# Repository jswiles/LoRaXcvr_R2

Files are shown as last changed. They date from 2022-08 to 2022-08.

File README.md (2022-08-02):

# LoRa Transceiver

LoRa Transceiver PCB for LoRa Remote Monitor System

- STM32L15x MPU : 
    - 256K FlashMemory
    - 32K SRAM
    - RTC Support - 32Khz Crystal

- HopeRF RFM95W LoRa Module 
    - US 915Mhz (FCC certified)

- TTL RS-232 Debug Port

- ST-LINK SWDIO Programming header

- Input Voltage   
    - 5.2 to 10 volts DC (500mA max)

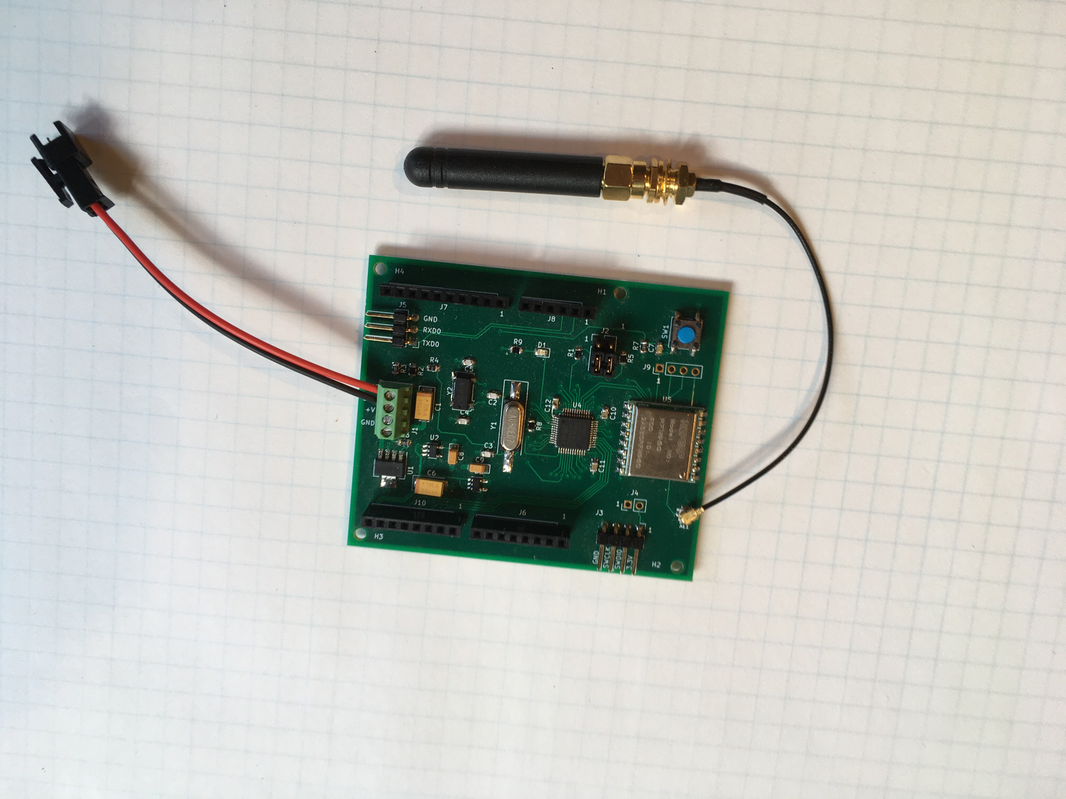
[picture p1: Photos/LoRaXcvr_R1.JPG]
LoRaXcvr_R1 Revision 1


Revision 1 

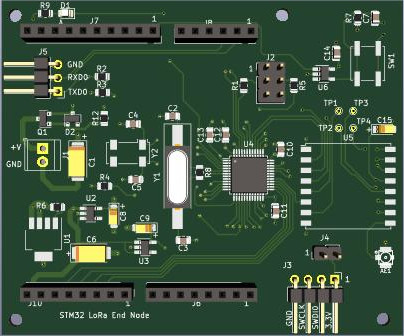
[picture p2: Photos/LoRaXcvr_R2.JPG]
LoRaXcvr_R2 Revision 2


Revision 2 3D Model

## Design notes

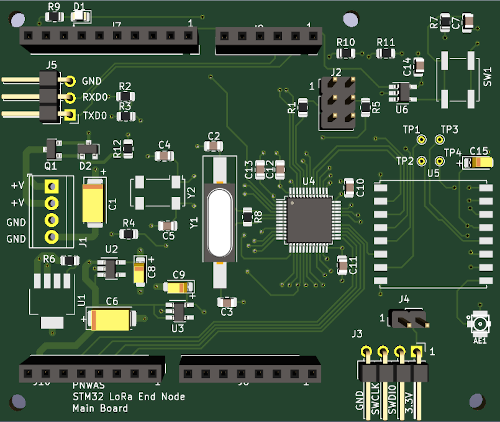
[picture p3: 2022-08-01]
Photos/LoRaXcvr_R2.png

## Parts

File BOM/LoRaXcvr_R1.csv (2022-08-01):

Reference | Quantity | Value | Footprint | Datasheet | DigiKey
AE1 | 1 | Antenna_Shield | connector-ufl:U.FL-COAX | ~ | CONUFL001-SMD-T
C1 C6 | 2 | 10uF | Capacitor_Tantalum_SMD:CP_EIA-6032-20_AVX-F_Pad2.25x2.35mm_HandSolder | ~ | 478-5804-1-ND
C10 C11 C12 C13 C14 | 5 | 0.1uF | Capacitor_SMD:C_0805_2012Metric | ~ | 311-1140-1-ND
C2 C3 C4 C5 | 4 | 20pF | Capacitor_SMD:C_0805_2012Metric | ~ | 399-8030-1-ND
C7 | 1 | .1uF | Capacitor_SMD:C_0805_2012Metric | ~ | 311-1140-1-ND
C8 C9 C15 | 3 | 10uF | Capacitor_Tantalum_SMD:CP_EIA-3216-18_Kemet-A_Pad1.58x1.35mm_HandSolder | ~ | 399-3684-1-ND
D1 | 1 | LED | LED_SMD:LED_0805_2012Metric | ~ | 754-1795-1-ND
D2 | 1 | BZX84Cxx | Diode_SMD:D_SOT-23_ANK | https://diotec.com/tl_files/diotec/files/pdf/datasheets/bzx84c2v4.pdf | 353-BZX84C10HE3-TPCT-ND
H1 H2 H3 H4 | 4 | MountingHole | MountingHole:MountingHole_2.5mm | ~
J1 | 1 | Screw_Terminal_01x04 | TerminalBlock_TE-Connectivity:TerminalBlock_TE_282834-4_1x04_P2.54mm_Horizontal | ~ | ED10563-ND
J2 | 1 | Conn_02x03_Odd_Even | Connector_PinHeader_2.54mm:PinHeader_2x03_P2.54mm_Vertical | ~ | 609-6338-ND
J3 | 1 | Conn_01x04 | Connector_PinHeader_2.54mm:PinHeader_1x04_P2.54mm_Horizontal | ~ | S1111EC-40-ND
J4 | 1 | Conn_01x02 | Connector_PinHeader_2.54mm:PinHeader_1x02_P2.54mm_Vertical | ~ | S1011EC-40-ND
J5 | 1 | Conn_01x03 | Connector_PinHeader_2.54mm:PinHeader_1x03_P2.54mm_Horizontal | ~ | S1111EC-40-ND
J6 J10 | 2 | Conn_01x08 | Connector_PinSocket_2.54mm:PinSocket_1x08_P2.54mm_Vertical | ~ | S1011EC-40-ND
J7 | 1 | Conn_01x10 | Connector_PinSocket_2.54mm:PinSocket_1x10_P2.54mm_Vertical | ~ | S1011EC-40-ND
J8 | 1 | Conn_01x06 | Connector_PinSocket_2.54mm:PinSocket_1x06_P2.54mm_Vertical | ~ | S1011EC-40-ND
Q1 | 1 | Q_PMOS_GSD | Package_TO_SOT_SMD:SOT-23 | ~ | SI2307CDS-T1-E3CT-ND
R1 R5 R12 | 3 | 100K | Resistor_SMD:R_0805_2012Metric | ~ | 541-CRCW0805100KJNEBCT-ND
R2 | 1 | 30K | Resistor_SMD:R_0805_2012Metric | ~ | 541-30KACT-ND
R4 R10 R11 | 3 | 0 | Resistor_SMD:R_0805_2012Metric | ~ | RMCF0805ZT0R00CT-ND
R3 R6 R7 | 3 | 10K | Resistor_SMD:R_0805_2012Metric | ~ | RMCF0805JT10K0CT-ND
R8 | 1 | 1M | Resistor_SMD:R_0805_2012Metric | ~ | 541-1.0MACT-ND
R9 | 1 | 510 | Resistor_SMD:R_0805_2012Metric | ~ | 541-510ACT-ND
SW1 | 1 | SW_Push | Button_Switch_SMD:SW_Push_1P1T_NO_CK_KSC6xxJ | ~ | CKN9112CT-ND
TP1 TP2 TP3 TP4 | 4 | TestPoint | TestPoint:TestPoint_THTPad_D1.0mm_Drill0.5mm | ~
U1 | 1 | LP38693MP-5.0 | Package_TO_SOT_SMD:SOT-223-5 | https://www.ti.com/lit/ds/symlink/lp38693.pdf | LP38693MPX-5.0/NOPBCT-ND
U2 U3 | 2 | AP2125K-3.3 | Package_TO_SOT_SMD:SOT-23-5_HandSoldering | https://www.diodes.com/assets/Datasheets/AP2127.pdf | AP2125K-3.3TRG1DICT-ND
U4 | 1 | STM32L152CCTx | Package_QFP:LQFP-48_7x7mm_P0.5mm | http://www.st.com/st-web-ui/static/active/en/resource/technical/document/datasheet/DM00048356.pdf | 497-17533-ND
U5 | 1 | RFM95W-915S2 | RF_Module:HOPERF_RFM9XW_SMD | https://www.hoperf.com/data/upload/portal/20181127/5bfcbea20e9ef.pdf | RFM95W-915S2-ND
U6 | 1 | MCP131X-2X | Package_TO_SOT_SMD:SOT-23-5_HandSoldering |  | MCP1319MT-29LE/OTCT-ND
Y1 | 1 | 8Mhz | Crystal:Crystal_SMD_HC49-SD_HandSoldering | ~ | 535-10212-1-ND
Y2 | 1 | 32.768KHz | Crystal:Crystal_SMD_Abracon_ABS25-4Pin_8.0x3.8mm | ~ | 535-13425-1-ND

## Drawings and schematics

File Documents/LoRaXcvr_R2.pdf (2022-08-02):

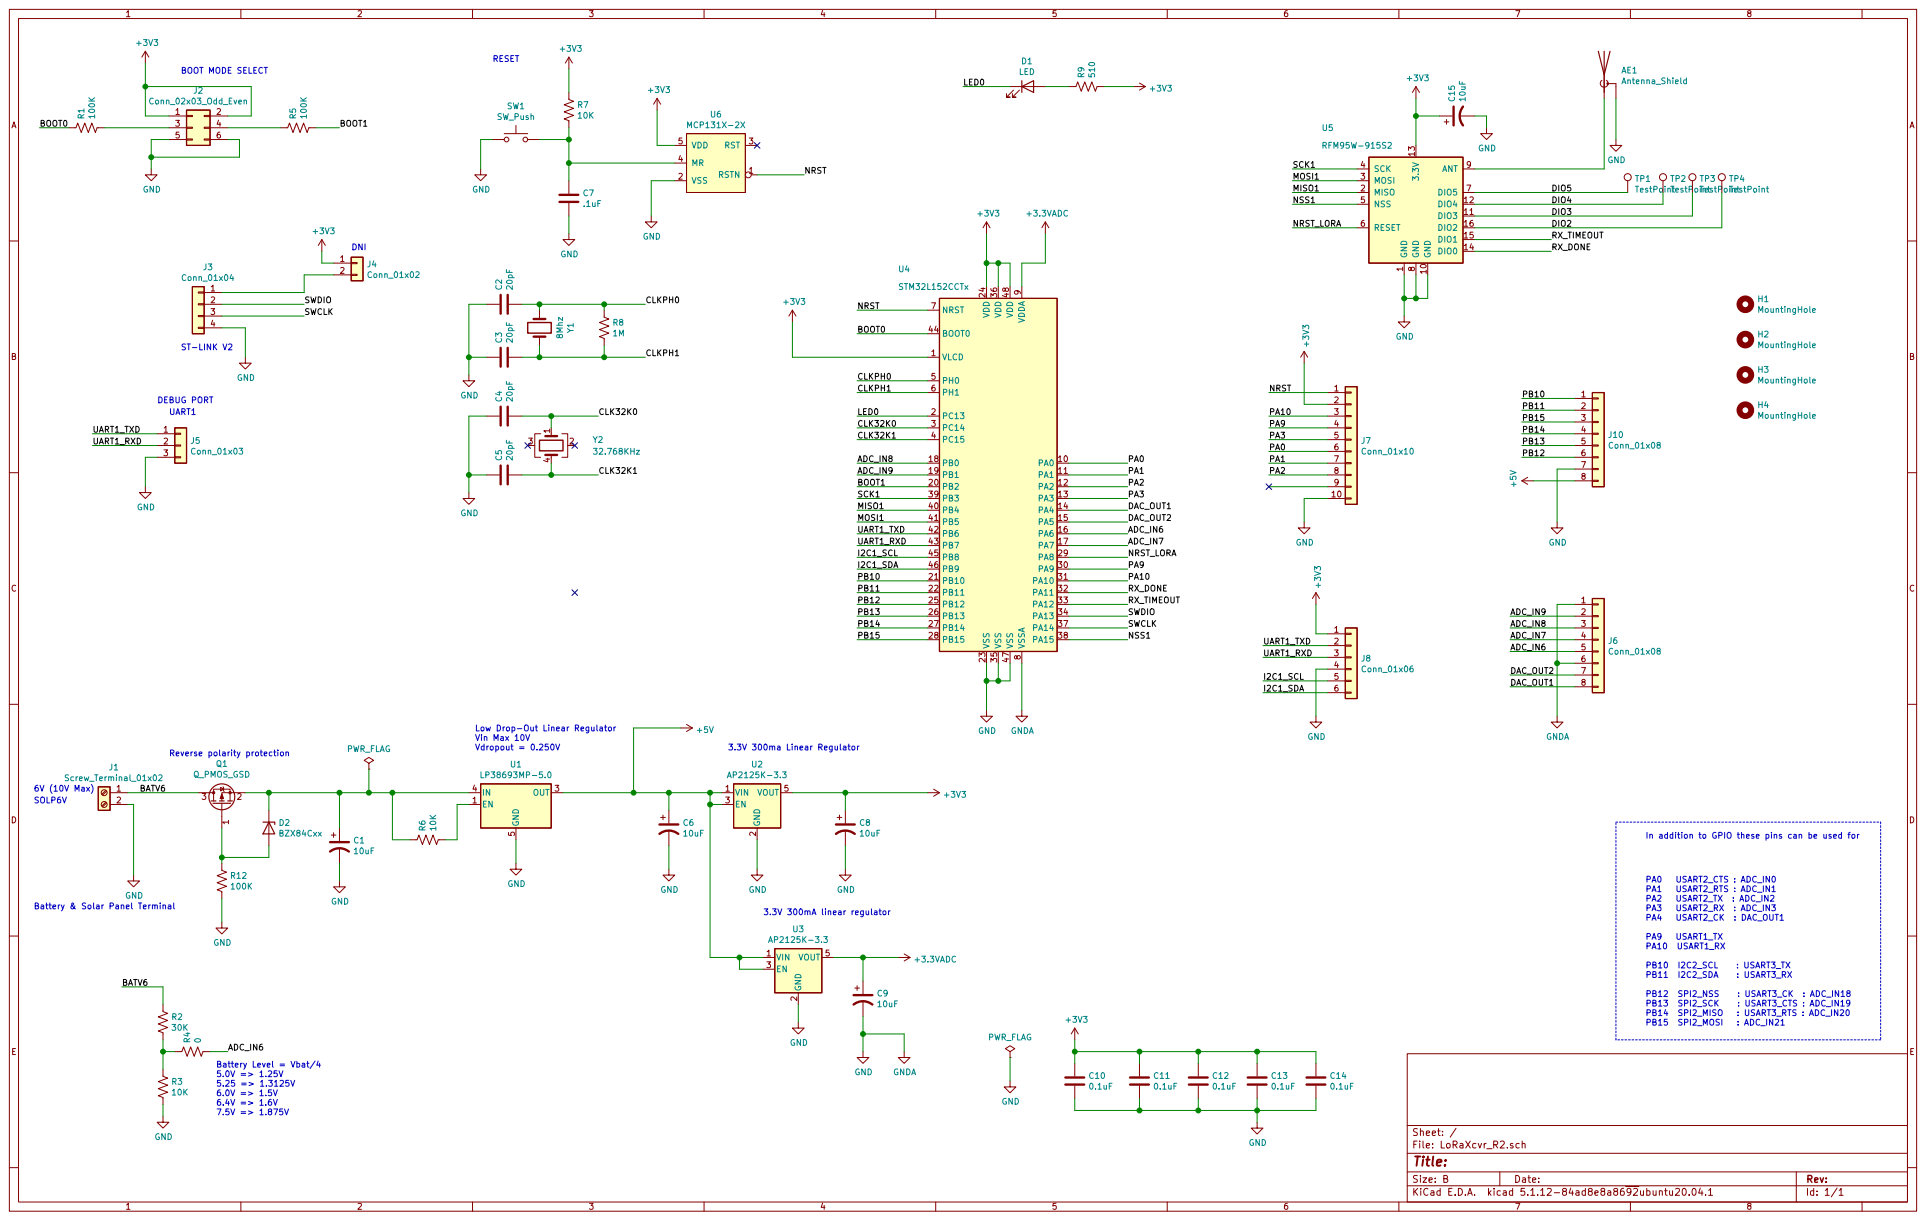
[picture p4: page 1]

1 GND 10 DIO3 11 DIO4 12 3.3V 13 DIO0 14 DIO1 15 DIO2 16 MISO 2 MOSI 3 SCK 4 NSS 5 RESET 6 DIO5 7 GND

9 VLCD 1 VSS 23 VSS 35 VSS 47 VSSA

Low Drop-Out Linear Regulator Vin Max 10V
Vdropout = 0.250V

In addition to GPIO these pins can be used for 3.3V 300mA linear regulator 3.3V 300ma Linear Regulator

2 EN 3 VOUT 5 U2 AP2125K-3.3 EN 1 OUT 3

Id: 1/1 Title: File: LoRaXcvr_R2.sch Sheet: /

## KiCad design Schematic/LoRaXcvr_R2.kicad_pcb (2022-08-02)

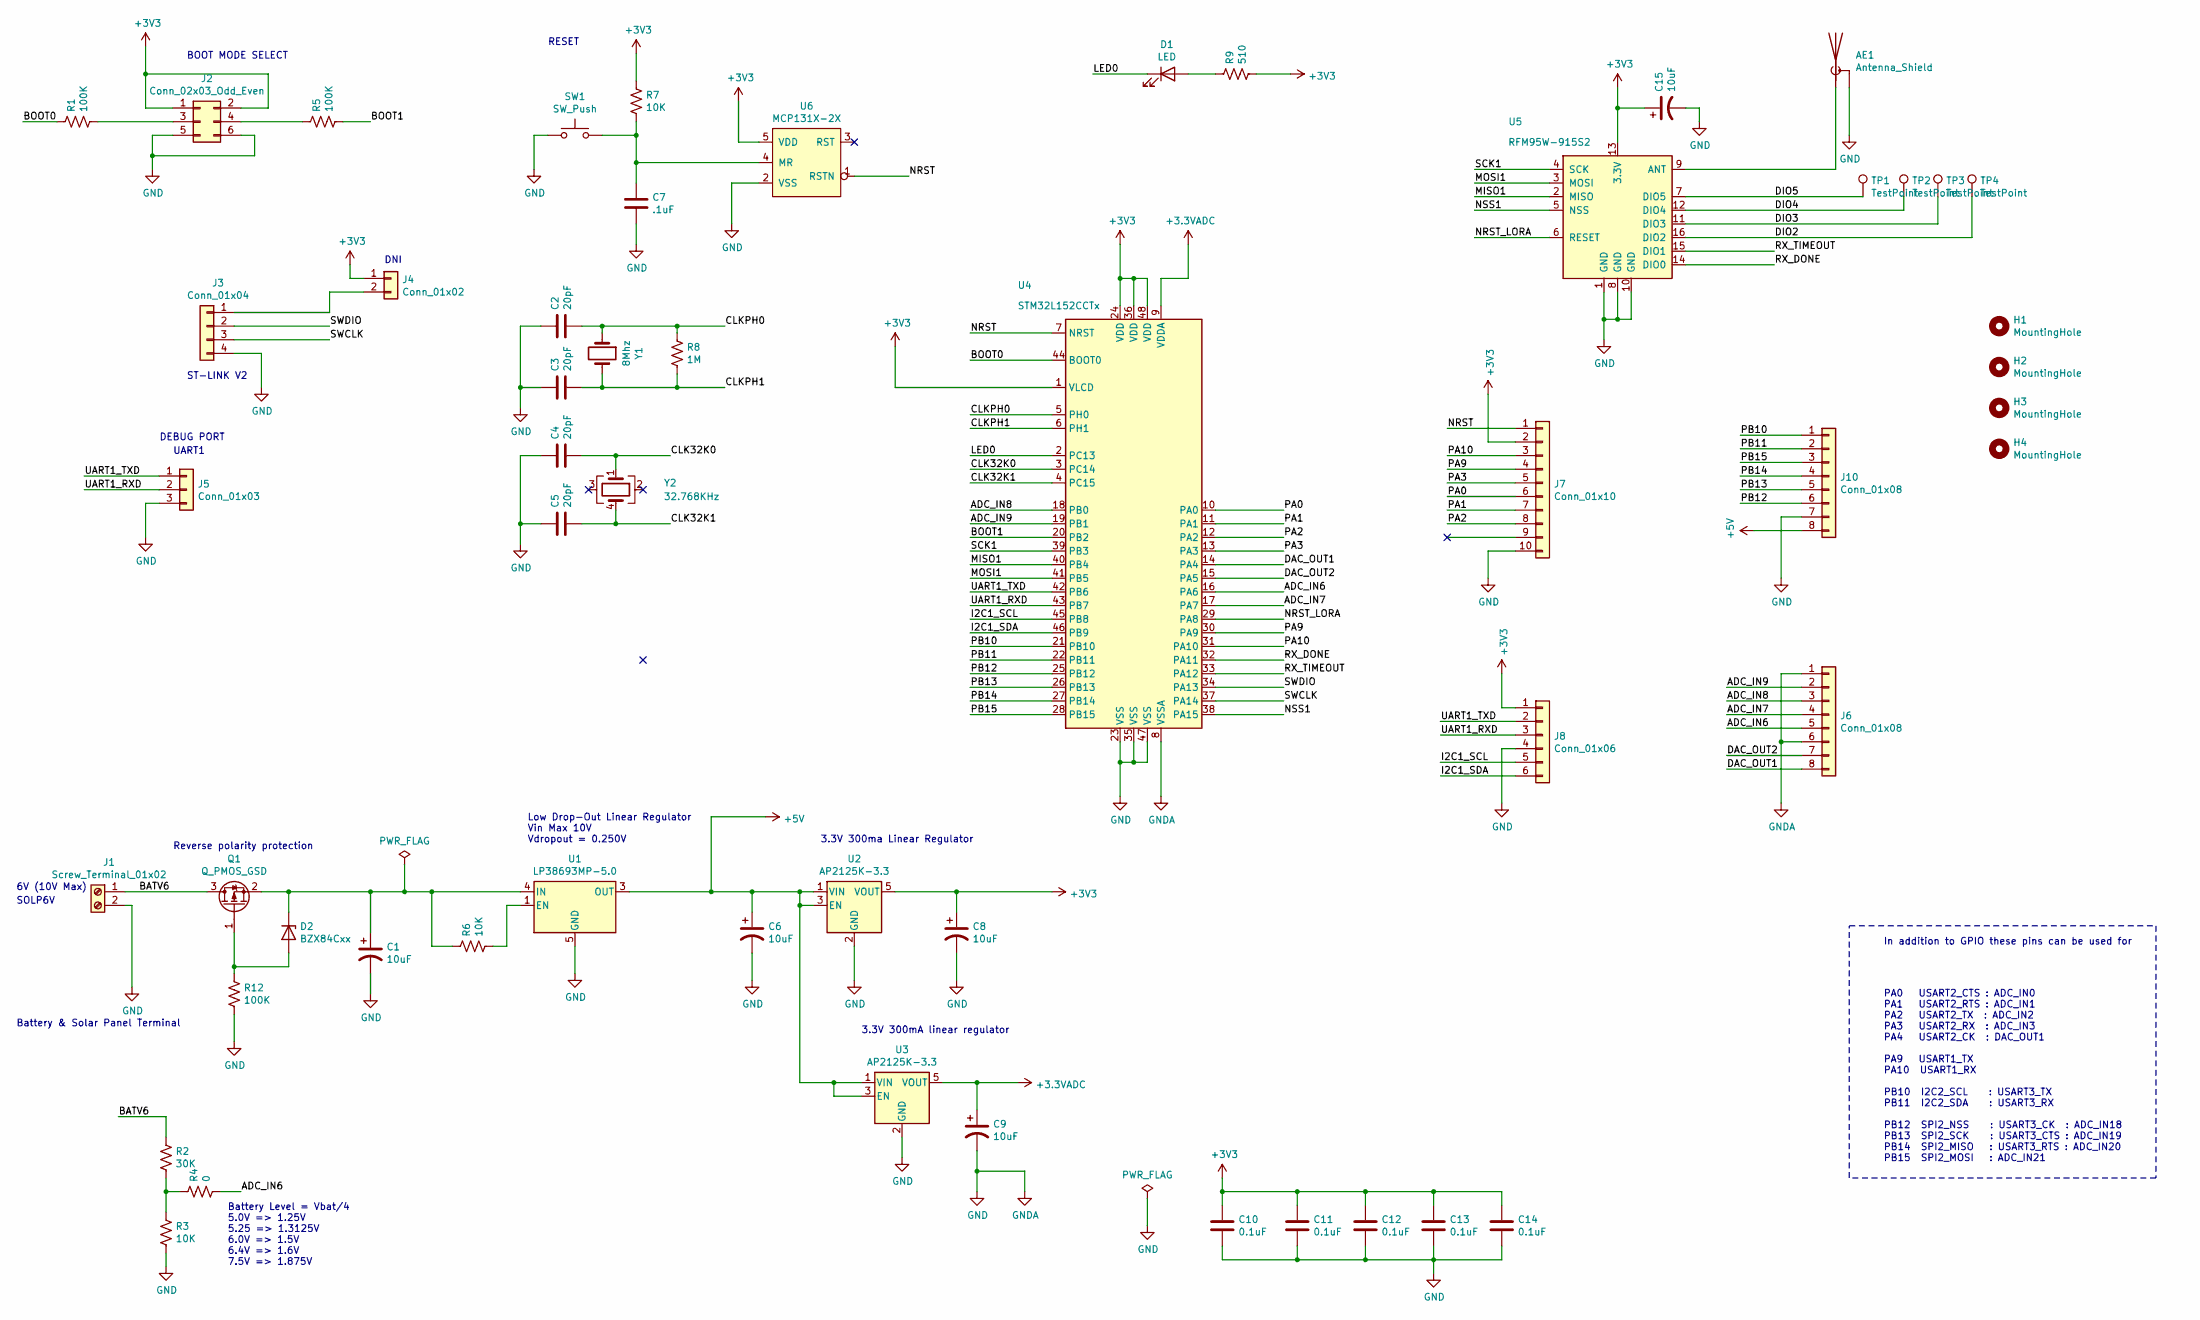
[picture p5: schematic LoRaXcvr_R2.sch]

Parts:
AE1: Antenna_Shield; U.FL-COAX; DigiKey CONUFL001-SMD-T
C1: 10uF; CP_EIA-6032-20_AVX-F_Pad2.25x2.35mm_HandSolder; DigiKey 478-5804-1-ND
C2, C3, C4, C5: 20pF; C_0805_2012Metric; DigiKey 399-8030-1-ND
C6: 10uF; CP_EIA-6032-20_AVX-F_Pad2.25x2.35mm_HandSolder
C7: .1uF; C_0805_2012Metric; DigiKey 311-1140-1-ND
C8, C9, C15: 10uF; CP_EIA-3216-18_Kemet-A_Pad1.58x1.35mm_HandSolder; DigiKey 399-3684-1-ND
C10, C11, C12, C13, C14: 0.1uF; C_0805_2012Metric; DigiKey 311-1140-1-ND
D1: LED; LED_0805_2012Metric; DigiKey 754-1795-1-ND
D2: BZX84Cxx; D_SOT-23_ANK; DigiKey 353-BZX84C10HE3-TPCT-ND
H1, H2, H3, H4: MountingHole; MountingHole_2.5mm
J1: Screw_Terminal_01x02; TerminalBlock_TE_282834-2_1x02_P2.54mm_Horizontal
J2: Conn_02x03_Odd_Even; PinHeader_2x03_P2.54mm_Vertical; DigiKey 609-6338-ND
J3: Conn_01x04; PinHeader_1x04_P2.54mm_Horizontal; DigiKey S1111EC-40-ND
J4: Conn_01x02; PinHeader_1x02_P2.54mm_Vertical; DigiKey S1011EC-40-ND
J5: Conn_01x03; PinHeader_1x03_P2.54mm_Horizontal; DigiKey S1111EC-40-ND
J6, J10: Conn_01x08; PinSocket_1x08_P2.54mm_Vertical; DigiKey S1011EC-40-ND
J7: Conn_01x10; PinSocket_1x10_P2.54mm_Vertical; DigiKey S1011EC-40-ND
J8: Conn_01x06; PinSocket_1x06_P2.54mm_Vertical; DigiKey S1011EC-40-ND
Q1: Q_PMOS_GSD; SOT-23; DigiKey SI2307CDS-T1-E3CT-ND
R1, R5, R12: 100K; R_0805_2012Metric; DigiKey 541-CRCW0805100KJNEBCT-ND
R2: 30K; R_0805_2012Metric; DigiKey 541-30KACT-ND
R3, R6, R7: 10K; R_0805_2012Metric; DigiKey RMCF0805JT10K0CT-ND
R4: 0; R_0805_2012Metric; DigiKey RMCF0805ZT0R00CT-ND
R8: 1M; R_0805_2012Metric; DigiKey 541-1.0MACT-ND
R9: 510; R_0805_2012Metric; DigiKey 541-510ACT-ND
SW1: SW_Push; SW_Push_1P1T_NO_CK_KSC6xxJ; DigiKey CKN9112CT-ND
TP1, TP2, TP3, TP4: TestPoint; TestPoint_THTPad_D1.0mm_Drill0.5mm
U1: LP38693MP-5.0; SOT-223-5; DigiKey LP38693MPX-5.0/NOPBCT-ND
U2: AP2125K-3.3; SOT-23-5_HandSoldering; DigiKey AP2125K-3.3TRG1DICT-ND
U3: AP2125K-3.3; SOT-23-5_HandSoldering; DigiKey AP2127K-3.3TRG1DICT-ND
U4: STM32L152CCTx; LQFP-48_7x7mm_P0.5mm; DigiKey 497-17533-ND
U5: RFM95W-915S2; HOPERF_RFM9XW_SMD; DigiKey RFM95W-915S2-ND
U6: MCP131X-2X; SOT-23-5_HandSoldering; DigiKey MCP1319MT-29LE/OTCT-ND
Y1: 8Mhz; Crystal_SMD_HC49-SD_HandSoldering; DigiKey 535-10212-1-ND
Y2: 32.768KHz; Crystal_SMD_Abracon_ABS25-4Pin_8.0x3.8mm; DigiKey 535-13425-1-ND

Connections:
+3.3VADC: C9.1, U3.5 (VOUT), U4.9 (VDDA)
+3V3: C8.1, C10.1, C11.1, C12.1, C13.1, C14.1, C15.1, J2.1, J2.2, J4.1, J7.2, J8.1, R7.1, R9.2, U2.5 (VOUT), U4.1 (VLCD), U4.24 (VDD), U4.36 (VDD), U4.48 (VDD), U5.13 (3.3V), U6.5 (VDD)
+5V: C6.1, J10.8, U1.3 (OUT), U2.1 (VIN), U2.3 (EN), U3.1 (VIN), U3.3 (EN)
/ADC_IN6: J6.5, R4.2, U4.16 (PA6)
/ADC_IN7: J6.4, U4.17 (PA7)
/ADC_IN8: J6.3, U4.18 (PB0)
/ADC_IN9: J6.2, U4.19 (PB1)
/BATV6: J1.1, Q1.3 (D), R2.1
/BOOT0: R1.1, U4.44 (BOOT0)
/BOOT1: R5.2, U4.20 (PB2)
/CLK32K0: C4.2, U4.3 (PC14), Y2.1
/CLK32K1: C5.2, U4.4 (PC15), Y2.4
/CLKPH0: C2.2, R8.1, U4.5 (PH0), Y1.1
/CLKPH1: C3.2, R8.2, U4.6 (PH1), Y1.2
/DAC_OUT1: J6.8, U4.14 (PA4)
/DAC_OUT2: J6.7, U4.15 (PA5)
/DIO2: TP4.1, U5.16 (DIO2)
/DIO3: TP3.1, U5.11 (DIO3)
/DIO4: TP2.1, U5.12 (DIO4)
/DIO5: TP1.1, U5.7 (DIO5)
/I2C1_SCL: J8.5, U4.45 (PB8)
/I2C1_SDA: J8.6, U4.46 (PB9)
/LED0: D1.1 (K), U4.2 (PC13)
/MISO1: U4.40 (PB4), U5.2 (MISO)
/MOSI1: U4.41 (PB5), U5.3 (MOSI)
/NRST: J7.1, U4.7 (NRST), U6.1 (RSTN)
/NRST_LORA: U4.29 (PA8), U5.6 (RESET)
/NSS1: U4.38 (PA15), U5.5 (NSS)
/PA0: J7.6, U4.10 (PA0)
/PA1: J7.7, U4.11 (PA1)
/PA2: J7.8, U4.12 (PA2)
/PA3: J7.5, U4.13 (PA3)
/PA9: J7.4, U4.30 (PA9)
/PA10: J7.3, U4.31 (PA10)
/PB10: J10.1, U4.21 (PB10)
/PB11: J10.2, U4.22 (PB11)
/PB12: J10.6, U4.25 (PB12)
/PB13: J10.5, U4.26 (PB13)
/PB14: J10.4, U4.27 (PB14)
/PB15: J10.3, U4.28 (PB15)
/RX_DONE: U4.32 (PA11), U5.14 (DIO0)
/RX_TIMEOUT: U4.33 (PA12), U5.15 (DIO1)
/SCK1: U4.39 (PB3), U5.4 (SCK)
/SWCLK: J3.3, U4.37 (PA14)
/SWDIO: J3.2, U4.34 (PA13)
/UART1_RXD: J5.2, J8.3, U4.43 (PB7)
/UART1_TXD: J5.1, J8.2, U4.42 (PB6)
GND: AE1.2 (Shield), C1.2, C2.1, C3.1, C4.1, C5.1, C6.2, C7.2, C8.2, C9.2, C10.2, C11.2, C12.2, C13.2, C14.2, C15.2, J1.2, J2.5, J2.6, J3.4, J5.3, J6.1, J6.6, J7.10, J8.4, J10.7, R3.2, R12.2, SW1.1, U1.5 (GND), U2.2 (GND), U3.2 (GND), U4.8 (VSSA), U4.23 (VSS), U4.35 (VSS), U4.47 (VSS), U5.1 (GND), U5.8 (GND), U5.10 (GND), U6.2 (VSS)
unnamed: AE1.1 (A), U5.9 (ANT)
unnamed: C1.1, D2.1 (K), Q1.2 (S), R6.1, U1.4 (IN)
unnamed: C7.1, R7.2, SW1.2, U6.4 (MR)
unnamed: D1.2 (A), R9.1
unnamed: D2.2 (A), Q1.1 (G), R12.1
unnamed: J2.3, R1.2
unnamed: J2.4, R5.1
unnamed: J3.1, J4.2
unnamed: R2.2, R3.1, R4.1
unnamed: R6.2, U1.1 (EN)

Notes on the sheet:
UART1
DEBUG PORT
Battery & Solar Panel Terminal
6V (10V Max)
SOLP6V
PA0 USART2_CTS : ADC_IN0 PA1 USART2_RTS : ADC_IN1 PA2 USART2_TX : ADC_IN2 PA3 USART2_RX : ADC_IN3 PA4 USART2_CK : DAC_OUT1 PA9 USART1_TX PA10 USART1_RX PB10 I2C2_SCL : USART3_TX PB11 I2C2_SDA : USART3_RX PB12 SPI2_NSS : USART3_CK : ADC_IN18 PB13 SPI2_SCK : USART3_CTS : ADC_IN19 PB14 SPI2_MISO : USA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
In addition to GPIO these pins can be used for
ST-LINK V2
BOOT MODE SELECT
RESET
3.3V 300ma Linear Regulator
3.3V 300mA linear regulator
Low Drop-Out Linear Regulator Vin Max 10V Vdropout = 0.250V
Battery Level = Vbat/4 5.0V => 1.25V 5.25 => 1.3125V 6.0V => 1.5V 6.4V => 1.6V 7.5V => 1.875V
DNI
Reverse polarity protection

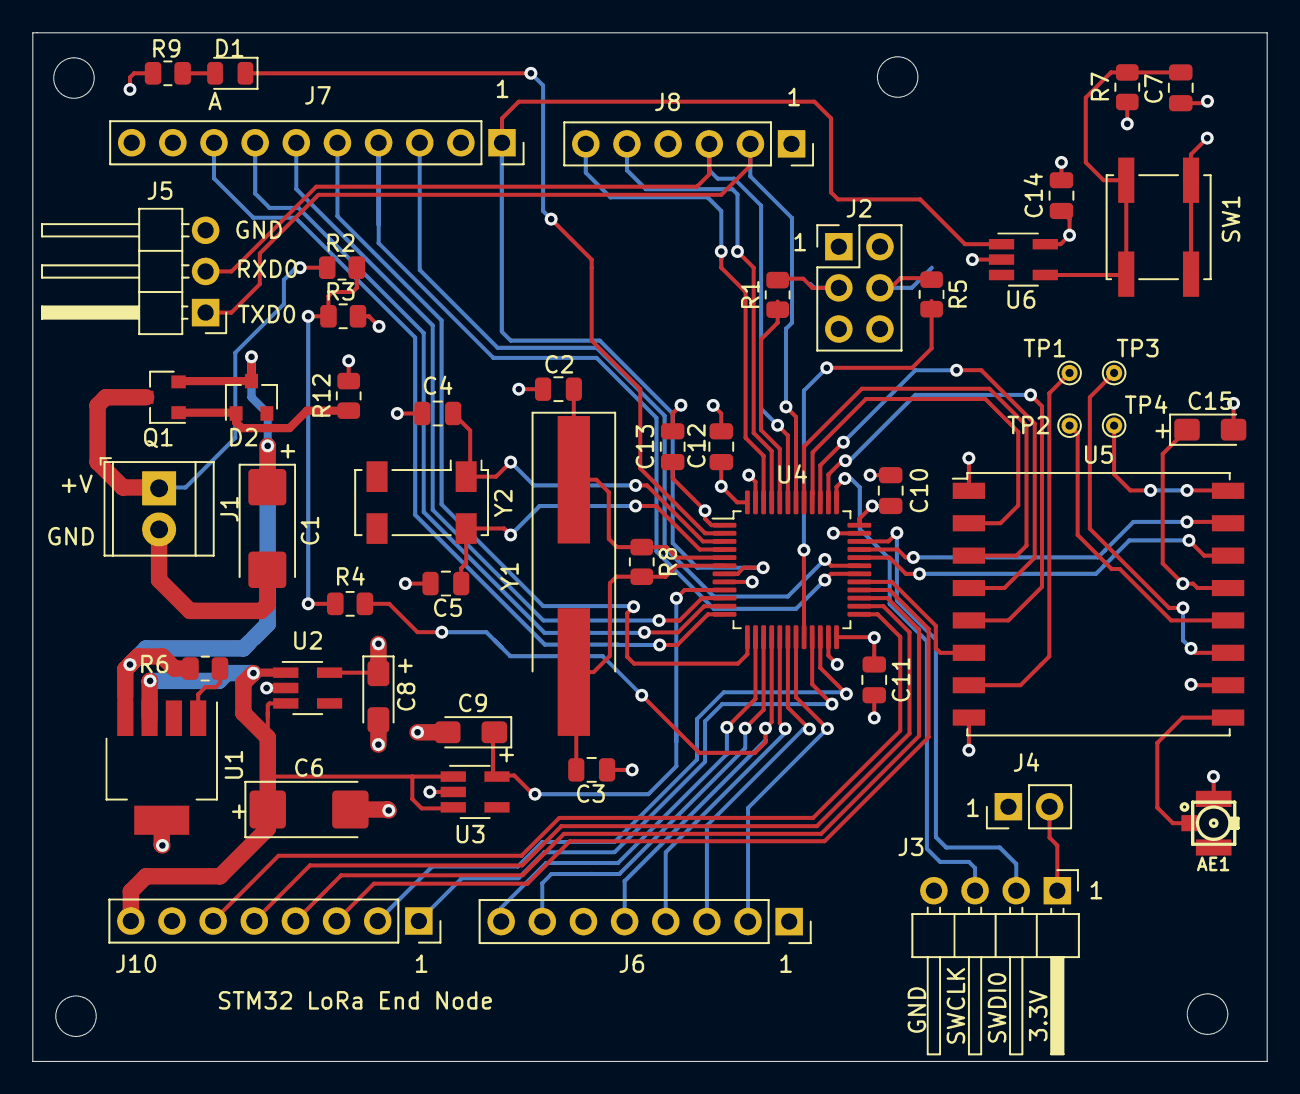
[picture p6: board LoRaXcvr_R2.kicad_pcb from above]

Board: 4 copper layers, 76.2 x 63.5 mm, 55 parts (0 on the bottom side), 58 nets.

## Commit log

2022-08-01 Add BOM
    [LoRaXcvr_R1.csv]
2022-08-01 Added PCB (gerber file) directory
    [LoRaXcvr_R2-B_Cu.gbr, LoRaXcvr_R2-B_Mask.gbr, LoRaXcvr_R2-B_Paste.gbr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]
2022-08-01 Added Schematic directory
    [LoRaXcvr_R2.kicad_pcb, LoRaXcvr_R2.sch]
2022-08-02 Updated R2 schematic and documents
    [LoRaXcvr_R2.kicad_pcb, LoRaXcvr_R2.sch]
